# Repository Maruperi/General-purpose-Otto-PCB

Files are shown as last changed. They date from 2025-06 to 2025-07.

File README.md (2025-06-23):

# General-purpose-Otto-PCB
This project consists on a PCB that can be used in every open source [Otto](https://www.printables.com/model/31955-otto-diy-build-your-own-robot?lang=es) model.

---
⚠️ **WARNING: WORK IN PROGRESS** ⚠️

This project is still under active development.  
Schematics and PCB layout may contain errors and are subject to change.  
**I do not recomend manufacturing any boards based on this design yet.**
---

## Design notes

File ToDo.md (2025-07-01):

## ToDo

- [x] Test buzzer.
- [x] Test ultrasonic sensor.
- [x] Test Bluetooth module  
  - [ ] Redisign Bluetooth module pins (pins are not correct; now the module should be soldered upside down)  
    > ⚠️ **Important notice:** If installed with the ICs of the module facing up, **GND and VCC will be reversed**, which can **damage or destroy the module**.
- [x] Test servo pins.
- [ ] Redisign power button PCB conections

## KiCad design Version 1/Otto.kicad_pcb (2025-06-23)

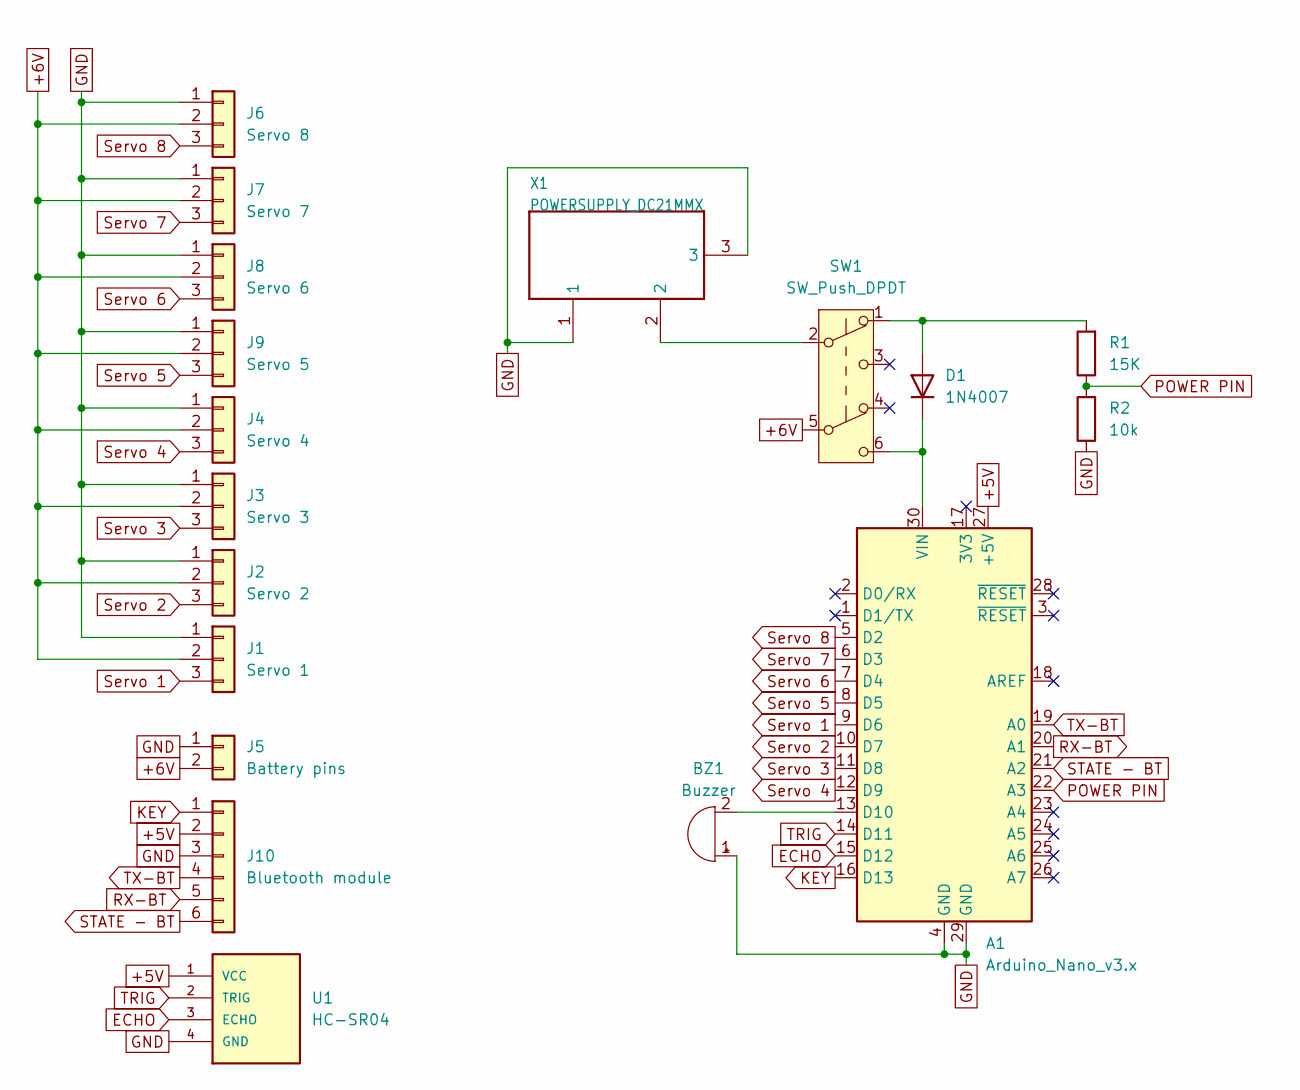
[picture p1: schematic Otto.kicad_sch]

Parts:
A1: Arduino_Nano_v3.x; Arduino_Nano
BZ1: Buzzer; Buzzer_12x9.5RM7.6
D1: 1N4007; D_DO-41_SOD81_P10.16mm_Horizontal
J1: Servo 1; PinHeader_1x03_P2.54mm_Vertical
J2: Servo 2; PinHeader_1x03_P2.54mm_Vertical
J3: Servo 3; PinHeader_1x03_P2.54mm_Vertical
J4: Servo 4; PinHeader_1x03_P2.54mm_Vertical
J5: Battery pins; PinHeader_1x02_P2.54mm_Vertical
J6: Servo 8; PinHeader_1x03_P2.54mm_Vertical
J7: Servo 7; PinHeader_1x03_P2.54mm_Vertical
J8: Servo 6; PinHeader_1x03_P2.54mm_Vertical
J9: Servo 5; PinHeader_1x03_P2.54mm_Vertical
J10: Bluetooth module; PinHeader_1x06_P2.54mm_Vertical
R1: 15K; R_Axial_DIN0207_L6.3mm_D2.5mm_P10.16mm_Horizontal
R2: 10k; R_Axial_DIN0207_L6.3mm_D2.5mm_P10.16mm_Horizontal
SW1: SW_Push_DPDT; SW_Push_2P2T_Toggle_CK_PVA2OAH5xxxxxxV2
U1: HC-SR04; XCVR_HC-SR04
X1: POWERSUPPLY_DC21MMX; POWERSUPPLY_DC-21MM

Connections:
+5V: A1.27 (+5V), J10.2, U1.1 (VCC)
+6V: J1.2, J2.2, J3.2, J4.2, J5.2, J6.2, J7.2, J8.2, J9.2, SW1.5 (B)
ECHO: A1.15 (D12), U1.3 (ECHO)
GND: A1.4 (GND), A1.29 (GND), BZ1.1 (+), J1.1, J2.1, J3.1, J4.1, J5.1, J6.1, J7.1, J8.1, J9.1, J10.3, R2.1, U1.4 (GND), X1.1, X1.3
KEY: A1.16 (D13), J10.1
unnamed: A1.13 (D10), BZ1.2 (-)
unnamed: A1.30 (VIN), D1.1 (K), SW1.6 (C)
unnamed: D1.2 (A), R1.2, SW1.1 (A)
unnamed: SW1.2 (B), X1.2
POWER PIN: A1.22 (A3), R1.1, R2.2
RX-BT: A1.20 (A1), J10.5
STATE - BT: A1.21 (A2), J10.6
Servo 1: A1.9 (D6), J1.3
Servo 2: A1.10 (D7), J2.3
Servo 3: A1.11 (D8), J3.3
Servo 4: A1.12 (D9), J4.3
Servo 5: A1.8 (D5), J9.3
Servo 6: A1.7 (D4), J8.3
Servo 7: A1.6 (D3), J7.3
Servo 8: A1.5 (D2), J6.3
TRIG: A1.14 (D11), U1.2 (TRIG)
TX-BT: A1.19 (A0), J10.4

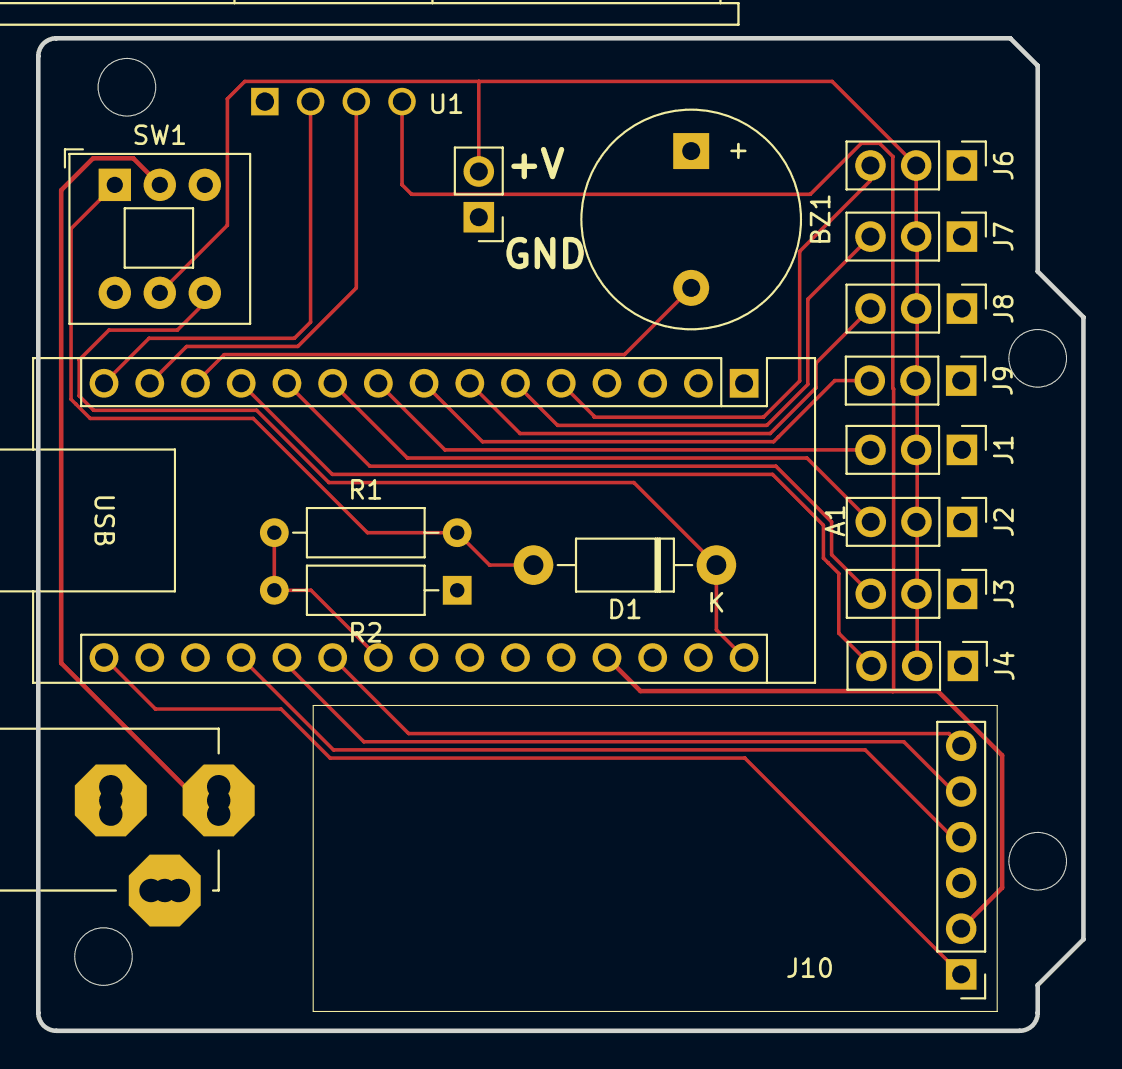
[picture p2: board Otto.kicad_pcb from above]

Board: 2 copper layers, 58.1 x 55.1 mm, 23 parts (0 on the bottom side), 22 nets.

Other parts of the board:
@HOLE0, @HOLE1, @HOLE2, @HOLE3: (no value)
U$1: DISCLAIMER

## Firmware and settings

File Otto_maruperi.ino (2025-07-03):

#include <Otto.h>

/* PIN DEFINITIONS */
// SERVOS
const short int LEFT_LEG = 6;
const short int RIGHT_LEG = 7;
const short int LEFT_FOOT = 8;
const short int RIGHT_FOOT = 9;

const short int BUZZER = 10;

// ULTRASONIC
const short int TRIGGER = 11;
const short int ECHO = 12;

/* OTHER DEFINITIONS */
Otto Otto;
bool messageShown = false;
const bool AUTO_MESSAGE = true;

const short int MOVEMENT_SPEED = 750; //range (500 - 3000)ms, the higher the value the slower the movements

enum Otto_States {
  IDLE,
  WALKING_FORWARD,
  WALKING_BACKWARD,
  TURNING_LEFT,
  TURNING_RIGHT
};

Otto_States currentState = IDLE;

/* AUXILIARY FUNCTIONS DEFINITIONS */
void Serial_UI();

/* MAIN PROGRAM */
void setup() {
  Serial.begin(9600);
  Otto.init(LEFT_LEG, RIGHT_LEG, LEFT_FOOT, RIGHT_FOOT, true, BUZZER);
  pinMode(TRIGGER, OUTPUT);
  pinMode(ECHO, INPUT); // Cambié a INPUT porque echo es entrada en ultrasonidos

  Otto.home();
}

void loop() {
  Serial_UI();

  switch (currentState) {
    case IDLE:
      Otto.home();
      break;
    case WALKING_FORWARD:
      Otto.walk(1, MOVEMENT_SPEED, 1);
      break;
    case WALKING_BACKWARD:
      Otto.walk(1, MOVEMENT_SPEED, -1);
      break;
    case TURNING_LEFT:
      Otto.turn(2, MOVEMENT_SPEED, 1);
      break;
    case TURNING_RIGHT:
      Otto.turn(2, MOVEMENT_SPEED, -1);
      break;

    default:
      break;
  }
}

/* AUXILIARY FUNCTIONS*/
void Serial_UI() {
  
  if (AUTO_MESSAGE && !messageShown) {
    Serial.println(F("--------------------------------------------------------------------------------------------------------------"));
    Serial.println(F("THIS PROGRAM WAS CREATED BY MARUPERI.\nGithub repository: https://github.com/Maruperi/General-purpose-Otto-PCB"));
    Serial.println(F("All pin definitions and more are in the \"Definitions.h\" file."));
    Serial.println(F("You can disable the previous messages on \"Definitions.h\" file (auto_message)..."));
    Serial.println(F("--------------------------------------------------------------------------------------------------------------"));
    messageShown = true;
  }

  while (Serial.available()) {
    char c = Serial.read();

    if (c == '\n' || c == '\r' || c == 0 || c == ' ') continue;

    switch (c) {
      case 'h':
        Serial.println(F("PRINT HELP COMMAND"));
        break;
      
      case 'i':
        Serial.println(F("Command i -> Idle..."));
        currentState = IDLE;
        break;
      case 'a':
        Serial.println(F("Command a -> Turning left..."));
        currentState = TURNING_LEFT;
        break;
      case 'w':
        Serial.println(F("Command w -> Walking forward..."));
        currentState = WALKING_FORWARD;
        break;
      case 's':
        Serial.println(F("Command s -> Walking backward..."));
        currentState = WALKING_BACKWARD;
        break;
      case 'd':
        Serial.println(F("Command d -> Turning right..."));
        currentState = TURNING_RIGHT;
        break;
      default:
        Serial.print(F("Unknown command: "));
        Serial.println(c);
    }
  }
}

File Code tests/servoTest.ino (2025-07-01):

#include <Servo.h>

#define num_of_servos 8
#define num_of_steps 1
#define delay_between_steps 15

Servo servo[num_of_servos];  // create Servo object as an array
int pins[num_of_servos] = {2, 3, 4, 5, 6, 7, 8, 9};
int pos = 0;

void setup() {
  for (int i = 0; i < 8; i++){
    servo[i].attach(pins[i]);
  }
  
}

void loop() {

  for (pos = 0; pos <= 180; pos += num_of_steps) {
    for (int i = 0; i < num_of_servos; i++) {
      servo[i].write(pos);
    }
    delay(delay_between_steps);
  }

  for (pos = 180; pos >= 0; pos -= num_of_steps) {
    for (int i = 0; i < num_of_servos; i++) {
      servo[i].write(pos);
    }
    delay(delay_between_steps);
  }

}

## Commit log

2025-06-23 Added version 1 Otto files
    This version includes:
    - Power jack port / pins for battery
    - On/Off switch
    - Bluetooth module
    - Buzzer
    - Ultrasonic sensor
    - 8 servo pins
    [Otto.kicad_pcb, Otto.kicad_sch]
2025-06-28 Added some test codes
    Added:
    - Ultrasonic sensor test code
    - Buzzer test code
    [buzzerTest.ino, ultrasonicTest.ino]
2025-07-01 Update ToDo.md
    Warning of reversed pins of the PCB (bluetooth module pins)
2025-07-01 Add servo test code
2025-07-01 Update ToDo.md
    - Redisign power button
    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
